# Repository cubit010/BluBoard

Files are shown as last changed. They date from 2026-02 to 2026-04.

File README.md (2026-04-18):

<h1 align="center">Bluboard</h1>
banner_ortho

An nRF52840 dev board made to be embedded in a custom mechanical keyboard, with as many pins broken out as possible within JLCPCB's 6-layer specs.

---

## What is this?

BluBoard is a custom nRF52840 development board built for use inside a mechanical keyboard. The main goal was to break out as many GPIO pins as possible and also having proper RF capabilities 
most off-the-shelf options such as the nice nano is powerful, but comes at high cost while having low gpio count, this board tries to fix that.

---

## Form Factor

Slightly wider than a Raspberry Pi Pico. Uses two 1×20 pin headers, plus an extra two 1×3 headers near the usb c port for the pins that didn't fit in the main rows.

---

## Features

- **nRF52840** - ARM Cortex-M4F, BLE 5.x, 1MB flash, 256KB RAM
- **USB-C** - power and programming
- **BLE 5.x** - wireless support built in with trace antenna
- **SWD debug header** - for debugging
- **I2C** - broken out, available on most pins
- **SPI** - broken out, available on most pins
- **Analog IO** - most analog pins are broken out, on top or bottom layer with 1oz copper for signal
- **6-layer PCB** - JLCPCB, ENIG finish, filled via for bga
- **Built-in power management** - built in battery support through a jst-ph connector and a BQ24075 charger

---

## Pin Breakout

Power, ground, and GPIO are spread across both 1×20 headers. The extra 1×3 headers cover the remaining pins and utils such as swd.

> Full pinout table coming soon. Check the KiCad schematic in the meantime.

---

## Firmware

BluBoard targets **ZMK**, which has native nRF52840 support and works well for wireless keyboards. Bare metal / Nordic SDK also works if you need it.

> A ZMK shield definition for BluBoard is planned but not yet published.

---

## Why 6 layers?

Jlc's manufacturing options allow for cheap manufacturing of 6 layer boards, in addition, at this form factor, their 6 layer boards are cheaper than 4 layer, while having additional benefits such as enig finish, and free filled vias, so the bga solder points would not be a possible point of failure

---

## Previews
### Schematic

(don't ask why I did this)



### PCB
#### All


#### Top


#### In.1


#### In.2


#### In.3


#### In.4


#### Bottom


*Built with KiCad 9 and 10 · Fabricated via JLCPCB · Part of Hack Club [Blueprint](blueprint.hackclub.com) and [Stasis](stasis.hackclub.com)*

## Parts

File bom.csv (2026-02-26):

Comment | Designator | Footprint | JLCPCB Part #
4.7nH | L1 | 0402 | C86065
32.768kHz | Y2 | Crystal_SMD_3215-2Pin_3.2x1.5mm | C97606
20pF | C18,C19 | 0402 | C1554
1uF | C21,C26,C30 | 0402 | C52923
0.5pF | C34 | 0402 | C1544
MCP1700x-300xxTT | U2 | SOT-23 | C39051
100pF | C24 | 0402 | C1546
15pF | C31,C32 | 0402 | C1548
PRTR5V0U2X | D87 | SOT-143 | C2827688
100nF | C1,C2,C23,C3,C7 | 0402 | C1525
5.1K | R1,R2 | 0402 | C25905
10k | R11,R12,R3 | 0402 | C25744
2K | R10 | 0402 | C4109
orange | D89 | 0805 | C84262
0.8pF | C33 | 0402 | C285068
4.7uF | C22,C25,C29 | 0603 | C19666
nRF52840 | U4 | Nordic_AQFN-73-1EP_7x7mm_P0.5mm | C190794
BQ24075RGT | U7 | VQFN-16-1EP_3x3mm_P0.5mm_EP1.6x1.6mm | C2865459
32Mhz | Y1 | Crystal_SMD_3225-4Pin_3.2x2.5mm | C9009
USB_C_Receptacle_USB2.0_14P | J1 | USB_C_Receptacle_HRO_TYPE-C-31-M-12 | C165948
SW_Push | SW1 | SW_Push_SPST_NO_Alps_SKRK | C720477

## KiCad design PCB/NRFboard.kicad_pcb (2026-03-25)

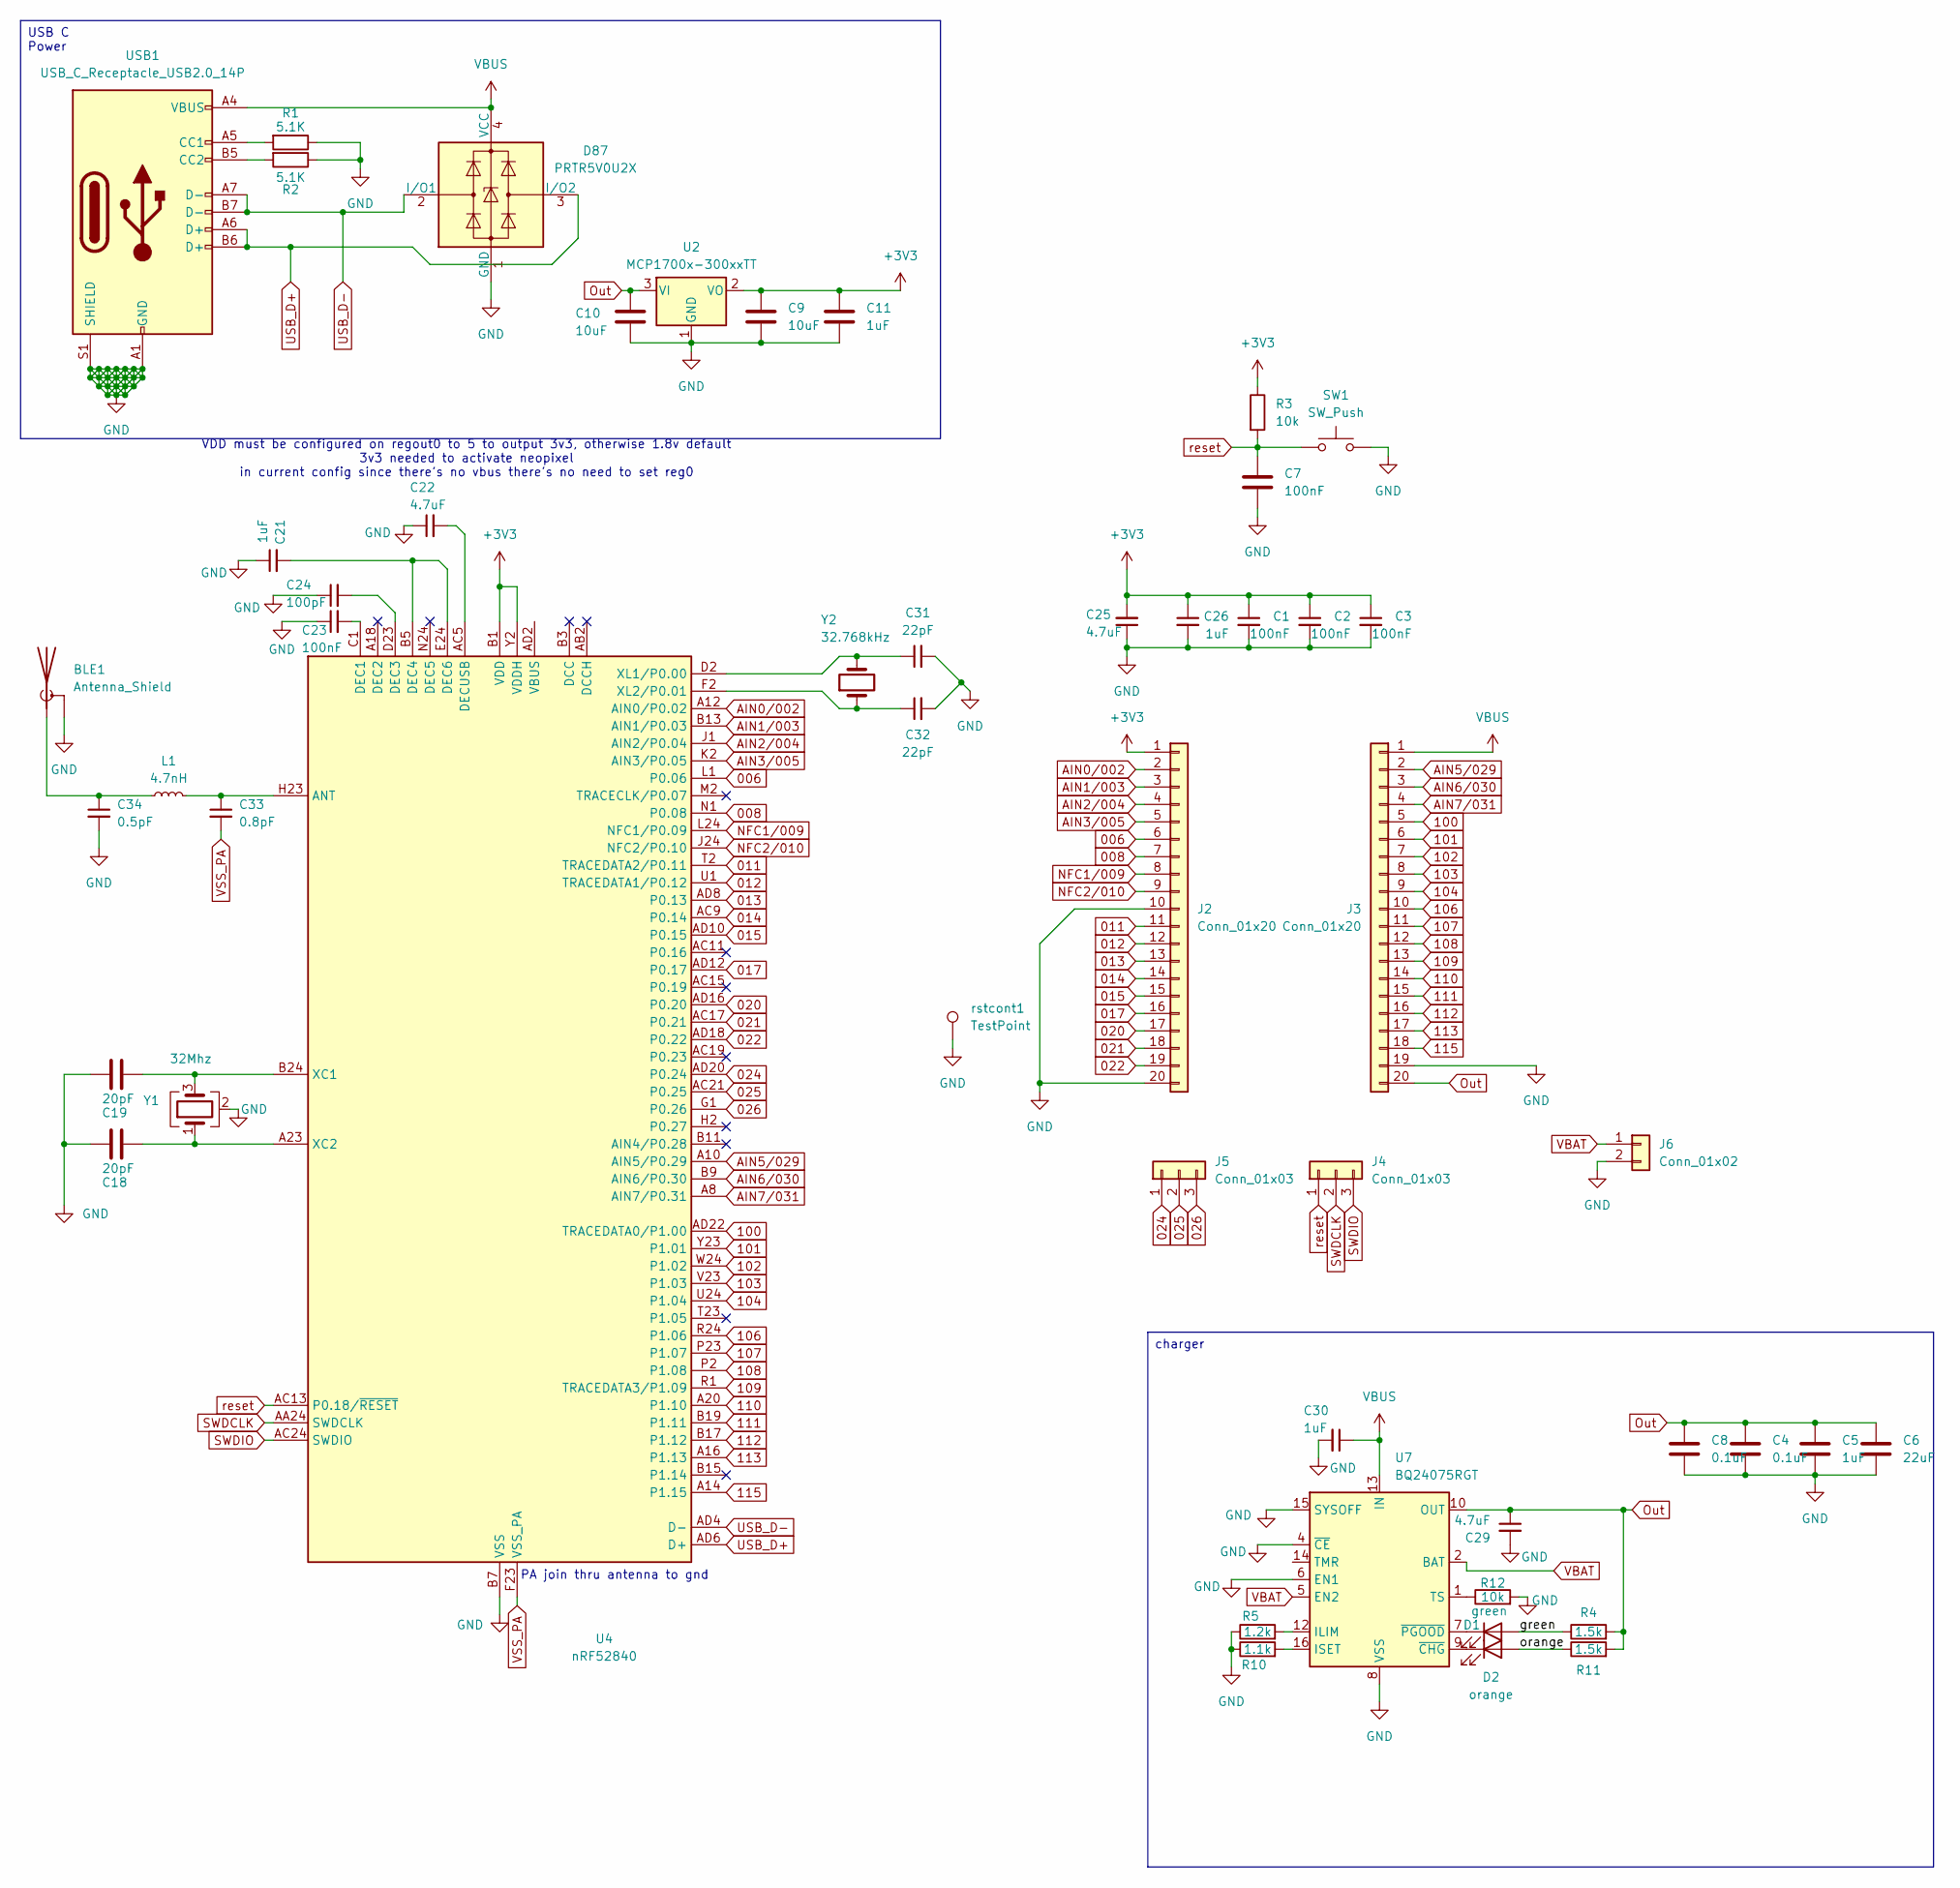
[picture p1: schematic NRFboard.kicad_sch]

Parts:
BLE1: Antenna_Shield; Texas_SWRA117D_2.4GHz_Right
C1, C2, C3, C7, C23: 100nF; C_0402_1005Metric
C4, C8: 0.1uF; C_0402_1005Metric
C5, C11, C21, C26, C30: 1uF; C_0402_1005Metric
C6: 22uF; C_0805_2012Metric
C9, C10: 10uF; C_0603_1608Metric
C18, C19: 20pF; C_0402_1005Metric
C22, C25, C29: 4.7uF; C_0603_1608Metric
C24: 100pF; C_0402_1005Metric
C31, C32: 22pF; C_0402_1005Metric
C33: 0.8pF; C_0402_1005Metric
C34: 0.5pF; C_0402_1005Metric
D1: green; LED_0805_2012Metric
D2: orange; LED_0805_2012Metric
D87: PRTR5V0U2X; SOT-143
J2, J3: Conn_01x20; PinHeader_1x20_P2.54mm_Vertical
J4, J5: Conn_01x03; PinHeader_1x03_P2.54mm_Vertical
J6: Conn_01x02; JST_PH_B2B-PH-K_1x02_P2.00mm_Vertical
L1: 4.7nH; L_0402_1005Metric
R1, R2: 5.1K; R_0402_1005Metric
R3, R12: 10k; R_0402_1005Metric
R4, R11: 1.5k; R_0402_1005Metric
R5: 1.2k; R_0402_1005Metric
R10: 1.1k; R_0402_1005Metric
SW1: SW_Push; SW_Push_SPST_NO_Alps_SKRK
U2: MCP1700x-300xxTT; SOT-23
U4: nRF52840; Nordic_AQFN-73-1EP_7x7mm_P0.5mm
U7: BQ24075RGT; VQFN-16-1EP_3x3mm_P0.5mm_EP1.6x1.6mm
USB1: USB_C_Receptacle_USB2.0_14P; USB_C_Receptacle_HRO_TYPE-C-31-M-12
Y1: 32Mhz; Crystal_SMD_3225-4Pin_3.2x2.5mm
Y2: 32.768kHz; Crystal_SMD_3215-2Pin_3.2x1.5mm
rstcont1: TestPoint; TestPoint_Pad_D1.0mm

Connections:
006: J2.6, U4.L1 (P0.06)
008: J2.7, U4.N1 (P0.08)
011: J2.11, U4.T2 (TRACEDATA2/P0.11)
012: J2.12, U4.U1 (TRACEDATA1/P0.12)
013: J2.13, U4.AD8 (P0.13)
014: J2.14, U4.AC9 (P0.14)
015: J2.15, U4.AD10 (P0.15)
017: J2.16, U4.AD12 (P0.17)
020: J2.17, U4.AD16 (P0.20)
021: J2.18, U4.AC17 (P0.21)
022: J2.19, U4.AD18 (P0.22)
024: J5.1, U4.AD20 (P0.24)
025: J5.2, U4.AC21 (P0.25)
026: J5.3, U4.G1 (P0.26)
100: J3.5, U4.AD22 (TRACEDATA0/P1.00)
101: J3.6, U4.Y23 (P1.01)
102: J3.7, U4.W24 (P1.02)
103: J3.8, U4.V23 (P1.03)
104: J3.9, U4.U24 (P1.04)
106: J3.10, U4.R24 (P1.06)
107: J3.11, U4.P23 (P1.07)
108: J3.12, U4.P2 (P1.08)
109: J3.13, U4.R1 (TRACEDATA3/P1.09)
110: J3.14, U4.A20 (P1.10)
111: J3.15, U4.B19 (P1.11)
112: J3.16, U4.B17 (P1.12)
113: J3.17, U4.A16 (P1.13)
115: J3.18, U4.A14 (P1.15)
+3V3: C1.1, C2.1, C3.1, C9.1, C11.1, C25.2, C26.1, J2.1, R3.1, U2.2 (VO), U4.A22 (VDD), U4.AD14 (VDD), U4.AD23 (VDD), U4.B1 (VDD), U4.W1 (VDD), U4.Y2 (VDDH)
/green: D1.2 (A), R4.1
/orange: D2.2 (A), R11.1
AIN0/002: J2.2, U4.A12 (AIN0/P0.02)
AIN1/003: J2.3, U4.B13 (AIN1/P0.03)
AIN2/004: J2.4, U4.J1 (AIN2/P0.04)
AIN3/005: J2.5, U4.K2 (AIN3/P0.05)
AIN5/029: J3.2, U4.A10 (AIN5/P0.29)
AIN6/030: J3.3, U4.B9 (AIN6/P0.30)
AIN7/031: J3.4, U4.A8 (AIN7/P0.31)
GND: BLE1.2 (Shield), C1.2, C2.2, C3.2, C4.2, C5.2, C6.2, C7.2, C8.2, C9.2, C10.1, C11.2, C18.1, C19.1, C21.1, C22.1, C23.1, C24.1, C25.1, C26.2, C29.2, C30.2, C31.2, C32.2, C34.2, D87.1 (GND), J2.10, J2.20, J3.19, J6.2, R1.1, R2.1, R5.1, R10.1, R12.2, SW1.2, U2.1 (GND), U4.B7 (VSS), U4.EP (VSS), U7.4 (~CE), U7.6 (EN1), U7.8 (VSS), U7.15 (SYSOFF), U7.17 (VSS), USB1.A1 (GND), USB1.A12 (GND), USB1.B1 (GND), USB1.B12 (GND), USB1.S1 (SHIELD), Y1.2 (G), Y1.4 (G), rstcont1.1 (1_1)
NFC1/009: J2.8, U4.L24 (NFC1/P0.09)
NFC2/010: J2.9, U4.J24 (NFC2/P0.10)
unnamed: BLE1.1 (A), C34.1, L1.1
unnamed: D1.1 (K), U7.7 (~PGOOD)
unnamed: D2.1 (K), U7.9 (~CHG)
unnamed: C33.1, L1.2, U4.H23 (ANT)
unnamed: C23.2, U4.C1 (DEC1)
unnamed: C24.2, U4.D23 (DEC3)
unnamed: C21.2, U4.B5 (DEC4), U4.E24 (DEC6)
unnamed: C22.2, U4.AC5 (DECUSB)
unnamed: C19.2, U4.B24 (XC1), Y1.3
unnamed: C18.2, U4.A23 (XC2), Y1.1
unnamed: C31.1, U4.D2 (XL1/P0.00), Y2.2
unnamed: C32.1, U4.F2 (XL2/P0.01), Y2.1
unnamed: R5.2, U7.12 (ILIM)
unnamed: R10.2, U7.16 (ISET)
unnamed: R12.1, U7.1 (TS)
unnamed: R1.2, USB1.A5 (CC1)
unnamed: R2.2, USB1.B5 (CC2)
Out: C4.1, C5.1, C6.1, C8.1, C10.2, C29.1, J3.20, R4.2, R11.2, U2.3 (VI), U7.10 (OUT), U7.11 (OUT)
SWDCLK: J4.2, U4.AA24 (SWDCLK)
SWDIO: J4.3, U4.AC24 (SWDIO)
USB_D+: D87.3 (I/O2), U4.AD6 (D+), USB1.A6 (D+), USB1.B6 (D+)
USB_D-: D87.2 (I/O1), U4.AD4 (D-), USB1.A7 (D-), USB1.B7 (D-)
VBAT: J6.1, U7.2 (BAT), U7.3 (BAT), U7.5 (EN2)
VBUS: C30.1, D87.4 (VCC), J3.1, U7.13 (IN), USB1.A4 (VBUS), USB1.A9 (VBUS), USB1.B4 (VBUS), USB1.B9 (VBUS)
VSS_PA: C33.2, U4.F23 (VSS_PA)
reset: C7.1, J4.1, R3.2, SW1.1, U4.AC13 (P0.18/~RESET)

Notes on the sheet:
VDD must be configured on regout0 to 5 to output 3v3, otherwise 1.8v default 3v3 needed to activate neopixel in current config since there's no vbus there's no need to set reg0
PA join thru antenna to gnd
charger
USB C Power

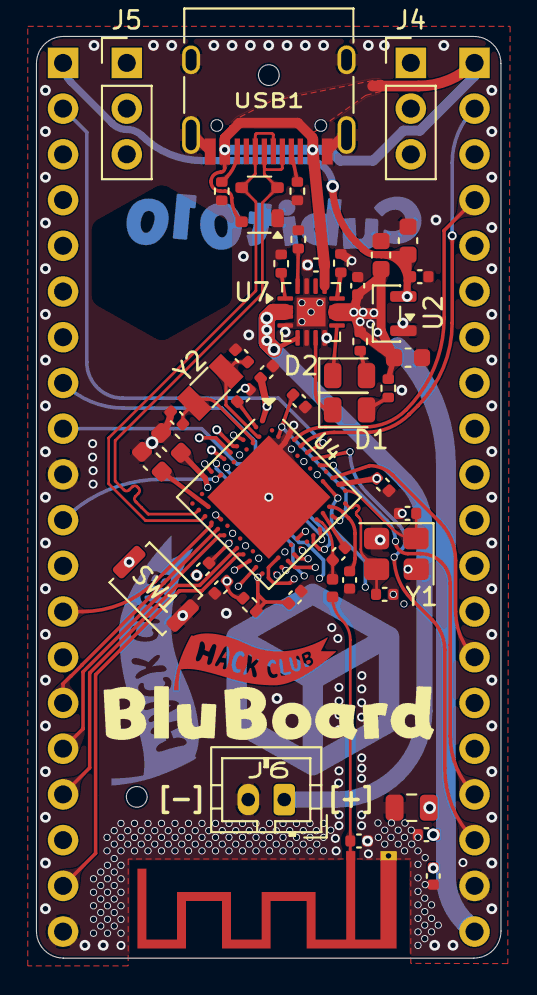
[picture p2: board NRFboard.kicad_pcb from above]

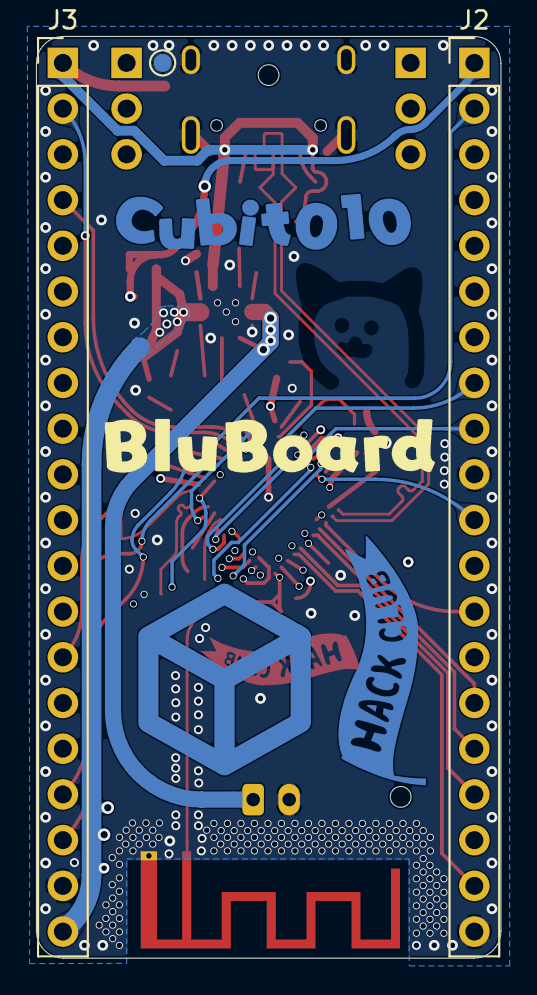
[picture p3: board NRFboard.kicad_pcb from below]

Board: 6 copper layers, 25.8 x 51.2 mm, 59 parts (8 on the bottom side), 67 nets.

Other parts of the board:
ToolHole1, ToolHole2: ToolingHole_1.152mm
car: car; carbig
cubit010lg: cubit010large
hackBack: hack
hacksm: hackSmall
logobig: logo; logoCU
logomid: logoCUmid

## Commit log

2026-02-26 update folder struct + csv
    [NRFboard.kicad_pcb, NRFboard.kicad_sch, bom.csv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]
2026-03-08 updated routing, should be finalized and ready for production
    [NRFboard.kicad_pcb, NRFboard.kicad_sch]
2026-03-22 update rf, wanted to add qspi but reverted
    [NRFboard.kicad_pcb, NRFboard.kicad_sch, bom.csv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]
2026-03-25 updated layout, added more vias, matched impedance for usb line for a coplanar diff
    [NRFboard.kicad_pcb, NRFboard.kicad_sch]
2026-04-18 Add README for BluBoard development board
    Added detailed information about the BluBoard, including features, form factor, pin breakout, firmware, and manufacturing details.
2026-04-18 Update README with power management details
    Added information about built-in power management and battery support.
